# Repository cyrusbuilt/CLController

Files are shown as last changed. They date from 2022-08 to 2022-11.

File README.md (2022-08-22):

# CLController

ESP8266-based Christmas Lights Controller (Arduino)



The code in this repository represents the firmware for the CLController main module, as well as some components for integrating with [OpenHAB3](https://openhab.org). CLController is a [PlatformIO](https://platformio.org) project and is meant to essentially a multi-module outlet controller, with the idea being that you can control multiple string of traditional Christmas light strings (this is not a pixel controller). Given the hardware design however, it is possible to use this device for multiple applications.  I can be monitored and controlled via [MQTT](https://mqtt.org).  Since there is an [ESP8266](https://www.adafruit.com/product/2471) at the heart of it, that means it is WiFi-enabled and is capable of OTA (Over-the-Air) firmware and configuration updates.

## Theory of Operation

CLController consists of one or more combinations of the following 3 hardware components:
- CLController Main Board
- CLController Relay Module
- CLController I/O Expansion Module

The bare-minimum configuration would be the CLController Main Board and (1) Relay Module.  Each relay module allows control of up to 8 circuits at 10A (MAX) per cicuit. The main control board allows up to (2) Relay Modules to be connected to it providing a total of 16 switched circuits.  You can expand this further by connecting an I/O expansion module (up to 7 max - providing a total of 128 possible relays max).  Each expansion module allows you to daisy chain another expansion module and also supports 2 more relay modules per expansion module. The expansion modules connect using the 2-Wire (I2C) bus and are address-configurable (the main control module is hard-wired for address 0x20).  Each expansion module is auto-detected and intialized during boot.

CLController uses a concept of "Playsheets" which is basically a JSON file containing a collection of sequences that fire the relays in the appropriate order at the appropriate time.  Each "sequence" contains a list of "states" followed by a delay in milliseconds.  Each "state" contains the relay module index, light string index (relay number), and state ("on/off").

The following is an example of the playsheet schema:

```json
{
    "name": "Example",
    "seq": [
        {
            "states": [
                {
                    "modIdx": 0,
                    "lsIdx": 1,
                    "lsState": "on"
                },
                ...
            ],
            "delayMs": 600
        },
        ...
    ]
}
```

- name = The play sheet name.
- seq = An array of sequences.
- states = An array of states.
- modIdx = Relay Module Index. 0 is the first relay module (port A on the main board).
- lsIdx = Light String Index. This is the index (address) of the relay to control (1 - 8).
- lsState = The state to set "on" or "off".
- delayMs = The delay in milliseconds before transitioning to the next state.

## IMPORTANT NOTE:

The size of the playsheet you can load will be limited to the amount of RAM available at runtime. If your playsheet (sequence file) is too large, it will fail to load when the controller boots and will report this condition to the serial console. In a future firmware release, the controller will also indicate this as it's status so it can be seen in the status payload published to MQTT and/or indicated using a flashing "RUN" LED or something like that.

## Architecture

CLController currently uses an ESP8266 MCU at it's heart. Unfortunately, the ESP8266 does not have a large number of GPIO pins. So to control the number of relays we need to, the main board (and the I/O expansion board) includes an MCP23017 2 port (8 GPIOs per port) I2C I/O expander paired with (2) ULN2803 Darlington arrays (each provides 8 outputs). The ULN2803s act as relay drivers. Thus allowing us to control up to 16 relays per expander. You can have a maximum of (8) MCP23017 chips on the I2C bus at a time, allowing for a grand total of 128 possible relays per CLController.  You can, of course, set up multiple CLController boards on your network allowing for even more control, but currently, the CLController boards do not communicate with each other and have no way of sharing playsheets. That being said.... if you need to control more than 128 strings of lights on one controller... you have a very impressive setup and an even more impressive utility bill. It's possible that you could break up the sequences across multiple playsheets and send each sheet to each CLController involved OTA, then send the run command to all the controllers over MQTT.  There might be timing issues depending on how long it takes each controller to recieve the command and begin executing though, but something to consider.

## Configuration

The config.h file contains default configuration directives. These options are the hardcoded default values that the system will initially boot with. However, if there is a config.json file present in the root of the SPIFFS file system, then it will override these defaults. Here we'll discuss each option:

- ENABLE_OTA: If you do not wish to support OTA updates, just comment this define.
- ENABLE_MDNS: If you do not wish to support [MDNS](https://tttapa.github.io/ESP8266/Chap08%20-%20mDNS.html), comment this define.
- ENABLE_TLS: If you wish to use TLS support (MQTT-over-SSL), uncomment this define.
- CONFIG_FILE_PATH: This is the path to the configuration file. The default is /config.json. The values in this file will override these defaults.
- DEFAULT_SSID: Change this line to reflect the SSID of your WiFi network.
- DEFAULT_PASSWORD: Change this line to reflect the password to your WiFi network.
- CLOCK_TIMEZONE: The GMT offset for your timezone (EST [America/New York] is -4 when observing DST. It's -5 when not.)
- SERIAL_BAUD: While it is not recommended, you can change the BAUD rate of the serial port here.
- CHECK_WIFI_INTERVAL: The interval (in milliseconds) to check to make sure the device is still connected to WiFi, and if not attempt to reconnect. Default is 30 seconds.
- CHECK_SENSORS_INTERVAL: The interval (in millisceonds) to check the water depth.
- CLOCK_SYNC_INTERVAL: The interval (in milliseconds) to try to resync the clock with NTP. Default is 1 hour.
- DEVICE_NAME: This essentially serves as the host name of the device on the network.
- CHECK_MQTT_INTERVAL: The interval (in milliseconds) to check connectivity to the MQTT broker. If the connection is lost, a reconnect will occur. The default value is 35 seconds.
- MQTT_TOPIC_STATUS: The MQTT status topic to publish device status messages to. Default is 'cysump/status'.
- MQTT_TOPIC_CONTROL: The MQTT control topic to subscribe to for control messages. Default is 'cysump/control'.
- MQTT_BROKER: The hostname or IP of the MQTT broker.
- MQTT_PORT: The port on the MQTT broker to connect to. The default is 8883 (default port for MQTT over TLS).
- OTA_HOST_PORT: Defines the port to listen for OTA updates on. This option is ignored if ENABLE_OTA is disabled.
- OTA_PASSWORD: The password used to authenticate with the OTA server. This option is ignored if ENABLE_OTA is disabled.
- ip: The default IP address. By default, this devices boots with a static IP configuration. The default IP is 192.168.0.202. You can change that here if you wish.
- gw: The default gateway address. The current default is 192.168.0.1. You can change that here if you wish.
- sm: The subnet mask. By default, it is 255.255.255.0, but you can change that here if need be.

To override the default configuration options, you need to upload a filesystem image containing a file named 'config.json' in the root of the SPIFFS filesystem. The file should like something like this:

```json
{
    "hostname": "CLCONTROLLER",
    "useDHCP": false,
    "ip": "192.168.0.202",
    "gateway": "192.168.0.1",
    "subnetMask": "255.255.255.0",
    "dnsServer": "192.168.0.1",
    "wifiSSID": "your_ssid_here",
    "wifiPassword": "your_password_here",
    "webserverPort": 80,
    "otaPort": 8266,
    "otaPassword": "your_ota_password_here",
    "mqttBroker": "your_mqtt_broker_here",
    "mqttPort": 8883,
    "mqttControlChannel": "clcontroller/control",
    "mqttStatusChannel": "clcontroller/status",
    "mqttUsername": "your_mqtt_username",
    "mqttPassword": "your_mqtt_password"
}
```

This configuration file is pretty self explanatory and one is included in the source. The file *MUST* be located in the "data" directory located in the root of the project in order to be picked up by the flash uploader (either via Serial or OTA). Each of the options in the configuration file are self-explanatory and match up with the hard-coded default settings mentioned above. If this file is not present when the firmware boots, a new file will be created and populated with the hardcoded defaults. These defaults can then be changed via the fail-safe menu and saved. You'll notice a couple of additional options in the config.json file not present in config.h. They are as follows:

- mqttUsername: If you have enabled password authentication on your MQTT broker, provide the username here.
- mqttPassword: If you have enabled password authentication on your MQTT broker, provide the password for the username above. If *both* the username and password are provided, then CLController will attempt to connect to the broker with the provided credentials; Otherwise, it will attempt to connect without credentials.
- mqttControlChannel: The MQTT control topic to subscribe to in order to receive device commands.
- mqttStatusChannel: The MQTT status topic to publish device status to.

## Getting Started

After you've configured everything the way you need it (as discussed above), build the firmware by either clicking "Build" in the PlatformIO tasks menu, or by opening a terminal to the project directory and typing:

```bash
> platformio run
```

NOTE: The first time you flash the Huzzah, you need to do so over serial (since the OTA code isn't there yet), but subsequent uploads can be done via OTA if configured properly.

The next thing to do is connect the Huzzah to your computer using an FTDI cable like [this one](https://www.adafruit.com/product/70?gclid=EAIaIQobChMIm7-50ZiZ5AIVlIvICh284QPxEAQYBCABEgJkcPD_BwE) and then configure the port in platformio.ini like so:

```ini
[env:huzzah]
monitor_speed = 115200
monitor_port = /dev/cu.usbserial-AL05HSL2  ; Change this to match your port if necessary
```

With the above mentioned FTDI cable attached to my MacBook, the port appears as it does in the config file above (usually PlatformIO is pretty good about auto-detecting the port for you).

Now all you have to do is flash the firmware onto the Huzzah. You can do this by first pressing and holding the "GPIO" button and then press the "reset" button and let go of both on the Huzzah to put it into flash mode (this is not necessary when you flash via OTA), then click the "Upload and Monitor" task in the PlatformIO menu or by typing the following into the terminal:

```bash
> platformio run --target upload
> platformio device monitor --baud 115200 --port /dev/cu.usbserial-AL05HSL2
```

Once complete, press the "reset" button on the Huzzah. You should see the device boot up in the serial console. Now put the device back into flash mode.  Configure the playsheet.json and config.json files as needed and click the "Upload File System Image" task in the PlatformIO menu. When finished, press the "reset" button again and the device will reboot and come back up with your new configuration settings.

## OTA Updates

If you wish to be able to upload firmware updates Over-the-Air, then besides leaving the ENABLE_OTA option uncommented, you will also need to uncomment all the upload_* lines in platformio.ini, and change the line 'upload_port = ' line to reflect the IP of the device and the line '--auth=' to reflect whatever OTA_PASSWORD is set to. Then when you click "upload" from the PlatformIO tasks (or if you execute 'platformio run --target upload' from the command line) it should upload directly over WiFi and once completed, the device will automatically flash itself and reboot with the new version. If you wish to upload a new configuration file, you can also do this via OTA. Assuming the above-mentioned settings are configured, you can then click "Upload File System Image" from the PlatformIO project tasks.

## Serial Console

If the device ever fails to connect to WiFi or if you press the 'I' key on your keyboard while in the serial console, normal operation of the device is suspended and the device will fall into a 'fail-safe' mode and present the user with a command menu, which can be use to re-configure the device, reboot, manually turn lights on and off, etc.

## Dependencies

The firmware dependencies will be installed automatically at compile-time. However, if you wish to install dependencies prior to compiling (for intellisense or to clear warnings/errors in the VSCode editor) you can run the following command:

```bash
> platformio lib install
```

## Actually controlling the Christmas lights

This is the dangerous part.  The generaly idea is to use the relays to switch strings of lights on and off.  There are a number of ways to do this:

1) Splice into the outlet wiring of an existing outlet/power strip/etc.
2) Cut one or more extension cords and wire into the relays.
3) Cut one of the power wires on the light strings themselves and wire into the relays.
4) Use a bussed electrical circuit that uses the relays to switch individual circuits (my preferred choice).

DISCLAIMER: You are dealing with HIGH VOLTAGE here.  Mains wiring is absolutely lethal and I AM NOT LIABLE for any injuries or death or damage to property as a result of any mistakes you or anyone else make implementing this controller in any way, shape, or form. If you don't know what you are doing, DON'T DO IT. Ask a qualified engineer or electrician to do this part for you. That being said, the way I did it was to mount all the electronics in an empty electrical box using stand-offs. Then I mounted 3 high-voltage electrical bus bars like those found in a breaker box. I then bought a heavy duty extension cord that can handle at least 15 Amps @ 120 Volts AC and cut the end off. I wired the 3 leads into the 3 different bus bars (which were mounted with sufficient distance from each other). Then I bought 16 lower-grade cheap extension cords and cut the plugs off and wired the ground and neutral wires into the matching bus bars. I wired the hot wire from each into the numbered terminals on the relays and then labeled each extension cord. I then cut pieces of heavy guage wire and used those to wire the COM on each relay to the Hot bus bar.  That way I can plug the box into a 15A outlet and then plug each string into the separate extension cord coming out of the box. (If you do this, you need to verify the outlet you are plugging into provides at least 15A and there is no other load on that circuit that would lead to an overload... It might even be worth adding a fuse to the input on the box to be extra safe).  This essentially creates power distribution box similar to a breaker box except you are using relays instead of breakers.

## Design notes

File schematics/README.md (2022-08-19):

# CLController Schematics

All files were produced using [EasyEDA](https://easyeda.com/). The following is a list of files and what they are:

- CLController/COM_CLController.csv - The bill of materials in CSV format.
- CLController/PCB_CLController.pdf - A PDF version of the PCB view.
- CLController/SCH_CLController.pdf - A PDF version of the schematic view.
- CLController/PCB_CLController.json - The original EasyEDA CAD file of the schematic.
- CLController/SCH_CLController.json - The original EasyEDA CAD file of the PCB.
- CLController/gerber - Subdirectory containing the exported Gerber files useful for importing into other CAD programs or for sending to fab houses that do not support EasyEDA files.
- ExpansionModule/* - All of the same things as above, but for the I/O expansion module.
- RelayModule/* - All of the same things as above, but for the relay module.

## NOTES

The MCU used in Rev 1.x of CLController is an Adafruit Huzzah ESP8266.  Future versions of CLController may switch to using an ESP32-based MCU because it is dual-core. Currently, (as is the case with most Arduino-compatible SoCs) there is only one core and only one main loop.  All processing happens on this main loop. While the playsheet processing loop is running, the other subsystems have to wait (task manager, MQTT message processing, OTA request processing, etc) until a sequence delay finishes. All subsystem operations are in their own loop so they can be called from the playsheet sequence processing loop as well as from the main loop() method. This way we can still process everything else, ableit delayed. A better solution would be to use a multi-core MCU like the ESP32 so that the sequence processing can execute on a separate core and not interfere with processing all the other subsystems.

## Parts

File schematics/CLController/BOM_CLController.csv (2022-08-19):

ID | Name | Designator | Footprint | Quantity | Manufacturer Part | Manufacturer | Supplier | Supplier Part | Price
1 | LED 5MM YELLOW | 1 | LED 5MM YELLOW | 1
2 | 100nF | C1,C2,C3,C4 | 100NF | 4 | CT4-0805Y104M500 | ReliaPro | LCSC | C46756
3 | 5mm | D1 | PKG-LED-5MM-RED | 1 | L-1503EC | KINGBRIGHT | Element14 | 1003201
4 | LED-GREEN-2.54-5mm | D2 | LED-GREEN-2.54-5MM-YUN | 1 | 503UOC
5 | Header-Male-2.54_1x6 | H1 | HDR-TH_6P-P2.54-V-M-1 | 1 | Header-Male-2.54_1x6 | BOOMELE | LCSC | C37208 | 0.028
6 | M023.5MM | JP1,JP2 | SCREWTERMINAL-3.5MM-2 | 2
7 | ICSP | P1,P2 | HDR-IDC-2.54-2X5P | 2 | IDC Box 2.54mm 2X5P | BOOMELE | LCSC | C5665 | 0.073
8 | 150 | R1 | PKG-0.25W RESISTOR | 1 | MCF 0.25W 150R | MULTICOMP | Element14 | 9339175
9 | KSH7079_4.7KΩ | R2 | KSH7079_4.7KR | 1 | MFR0W4F2200A50 | UniOhm | EasyEDA | E57439
10 | MCP23017-E/SP | U1 | DIP-28_L35.0-W6.5-P2.54-LS7.6-BL | 1 | MCP23017-E/SP | Microchip Tech | LCSC | C647352 | 2.279
11 | Huzzah ESP8266 Breakout_TT | U2 | HUZZAH 8266 | 1 |  | Adafruit
12 | ULN2803APG | U3,U4 | ULN2803APG | 2 | ULN2803APG | TOSHIBA | LCSC | C5252

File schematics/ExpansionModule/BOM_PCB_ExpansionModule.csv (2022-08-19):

ID | Name | Designator | Footprint | Quantity | Manufacturer Part | Manufacturer | Supplier | Supplier Part | Price
1 | 100nF | C1,C2,C3,C4 | 100NF | 4 | CT4-0805Y104M500 | ReliaPro | LCSC | C46756
2 | M023.5MM | JP1,JP2,JP3 | SCREWTERMINAL-3.5MM-2 | 3
3 | ICSP | P1,P2 | HDR-IDC-2.54-2X5P | 2 | IDC Box 2.54mm 2X5P | BOOMELE | LCSC | C5665 | 0.073
4 | KSH7079_4.7KΩ | R3,R1,R2 | KSH7079_4.7KR | 3 | MFR0W4F2200A50 | UniOhm | EasyEDA | E57439
5 | 150 | R4 | PKG-0.25W RESISTOR | 1 | MCF 0.25W 150R | MULTICOMP | Element14 | 9339175
6 | MCP23017-E/SP | U1 | DIP-28_L35.0-W6.5-P2.54-LS7.6-BL | 1 | MCP23017-E/SP | Microchip Tech | LCSC | C647352 | 2.279
7 | 5mm | D1 | PKG-LED-5MM-RED | 1 | L-1503EC | KINGBRIGHT | Element14 | 1003201
8 | HEADER MALE 1X3 | J1,J2,J3,J4,J5 | HEADER MALE OR FEMALE PINS 1X3 | 5
9 | ULN2803APG | U2,U3 | ULN2803APG | 2 | ULN2803APG | TOSHIBA | LCSC | C5252
10 | 470 | R5 | RESISTOR 1/4 WATT 470 OHM | 1
11 | LM317T | U4 | TO-220 (LM317T) | 1 | LM317T | ON | Mouser | 511-LM317T
12 | 100uF 25v | C6 | 100UF/25V | 1 | -
13 | 330 | R6 | RESISTOR 1/4 WATT 330 OHM | 1
14 | 75Ω(75R0) | R7 | AXIAL-0.3 | 1 | MF1/8W-75Ω±1% T52 | CCO | LCSC | C119155 | 0.008
15 | 10uF | C5 | CAP-10UF-50V-CHONGX | 1 | 10uF 50V白纸 13*25 | ValuePro | LCSC | C43814 | 0.155

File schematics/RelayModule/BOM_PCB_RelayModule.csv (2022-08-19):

ID | Name | Designator | Footprint | Quantity | Manufacturer Part | Manufacturer | Supplier | Supplier Part | Price
1 | G5LE-14 5VDC | K1,K2,K3,K4,K5,K6,K7,K8 | RELAY-TH_G5LE-14-XX | 8 | - | Omron Electronics | LCSC | C116963 | 1.646
2 | LED-GREEN-2.54-5mm | D1,D2,D3,D4,D5,D6,D7,D8 | LED-GREEN-2.54-5MM-YUN | 8 | 503UOC
3 | 5mm | D9 | PKG-LED-5MM-RED | 1 | L-1503EC | KINGBRIGHT | Element14 | 1003201
4 | ICSP | P1 | HDR-IDC-2.54-2X5P | 1 | IDC Box 2.54mm 2X5P | BOOMELE | LCSC | C5665 | 0.073
5 | M023.5MM | JP1,JP2,JP3,JP4,JP5,JP6,JP7,JP8 | SCREWTERMINAL-3.5MM-2 | 8
6 | 4114R-002-151 | IC1 | DIP-14_L17.8-W10.2-P2.54-BL | 1 | 100-143-200-1001-00 | Nextron(台湾正凌) | LCSC | C2846065 | 0.252

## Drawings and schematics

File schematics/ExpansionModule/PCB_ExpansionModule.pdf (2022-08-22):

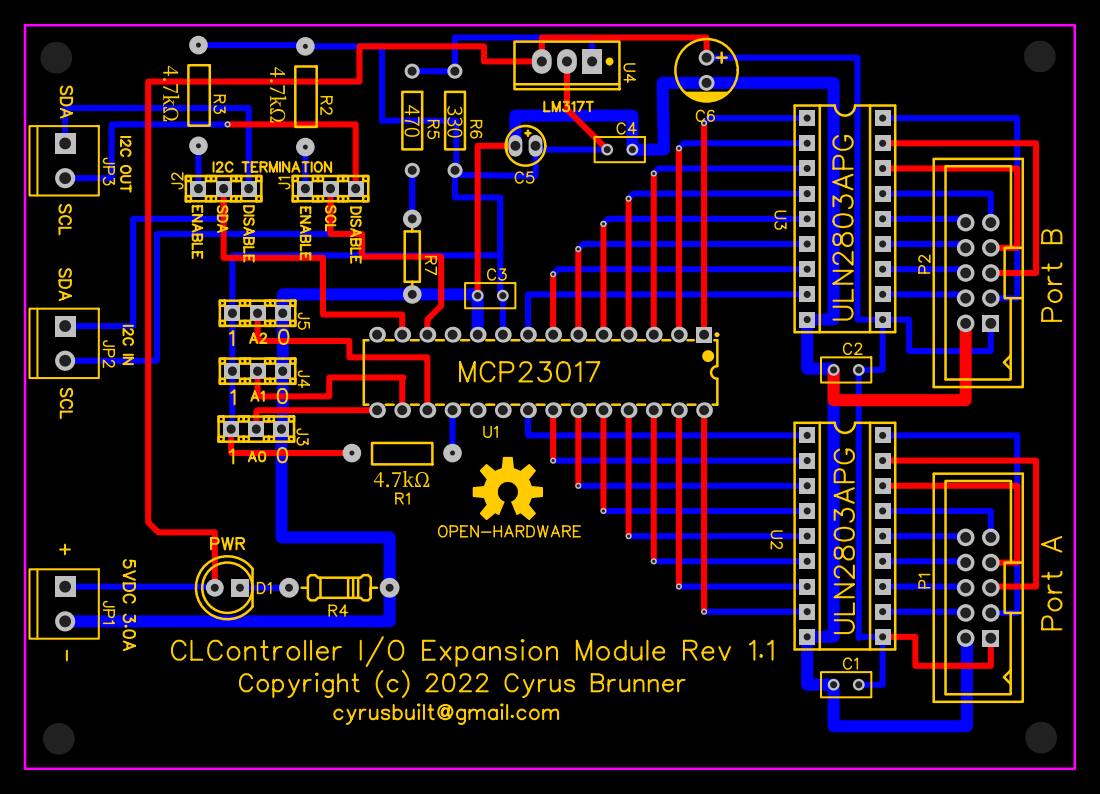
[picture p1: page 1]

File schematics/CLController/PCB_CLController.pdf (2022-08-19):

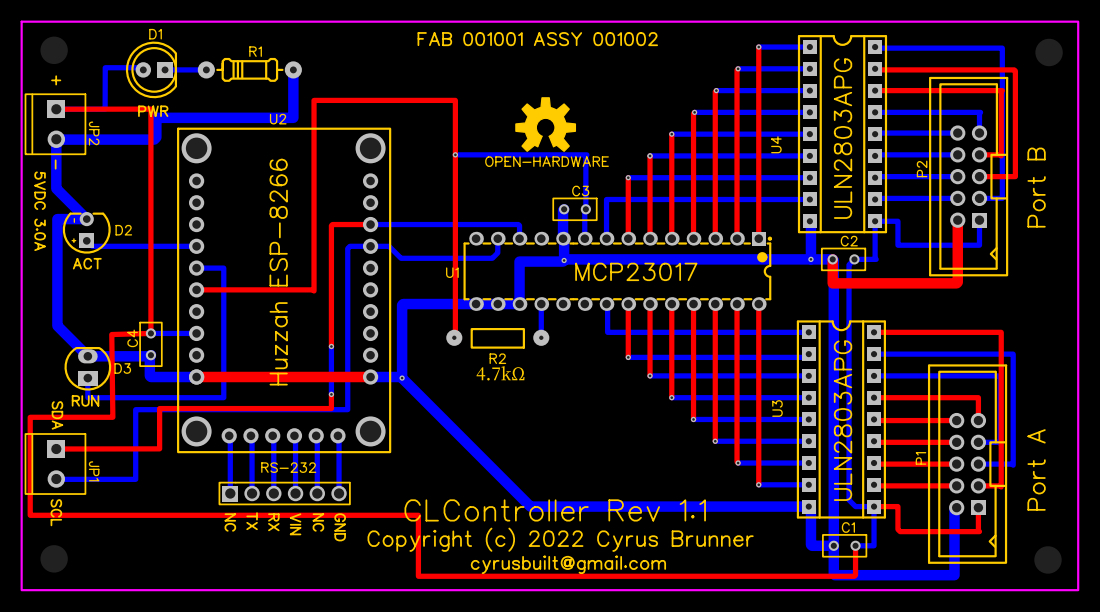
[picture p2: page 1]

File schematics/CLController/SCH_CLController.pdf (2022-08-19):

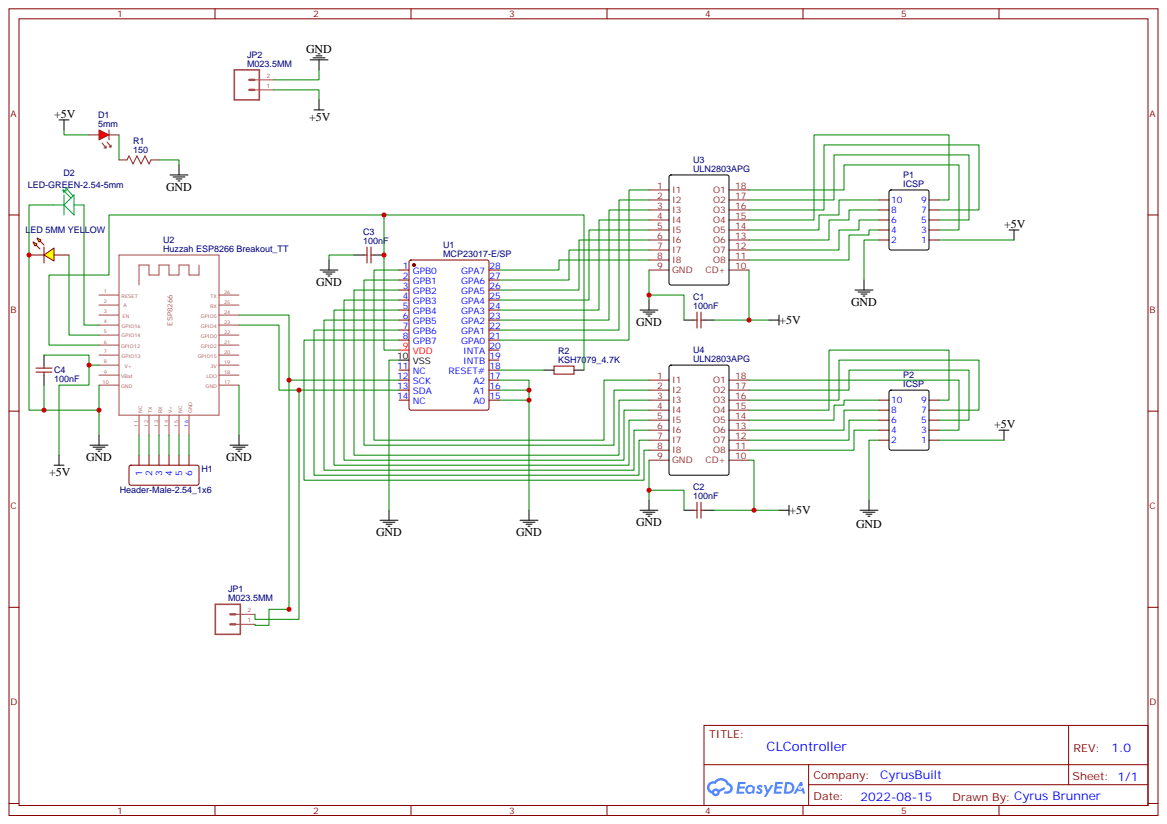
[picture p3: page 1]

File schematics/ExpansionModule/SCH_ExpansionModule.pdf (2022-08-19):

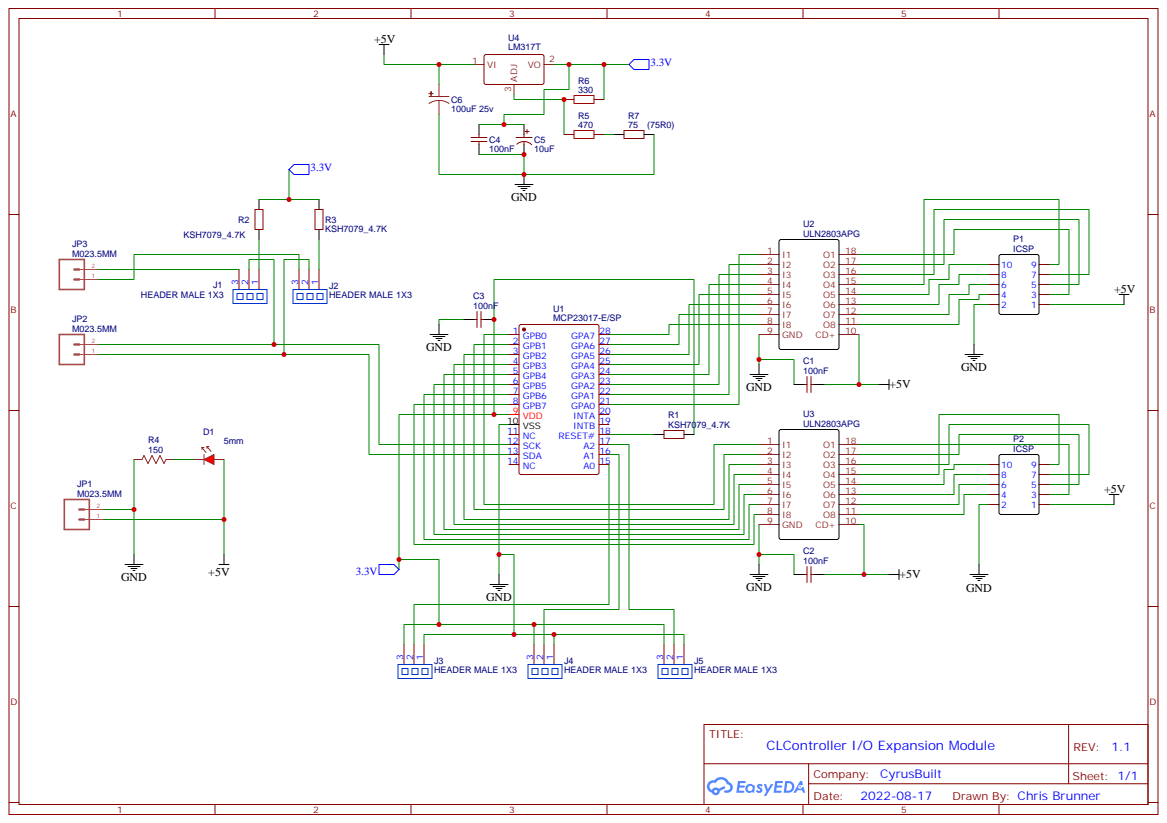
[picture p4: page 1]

Drawn By: Chris Brunner

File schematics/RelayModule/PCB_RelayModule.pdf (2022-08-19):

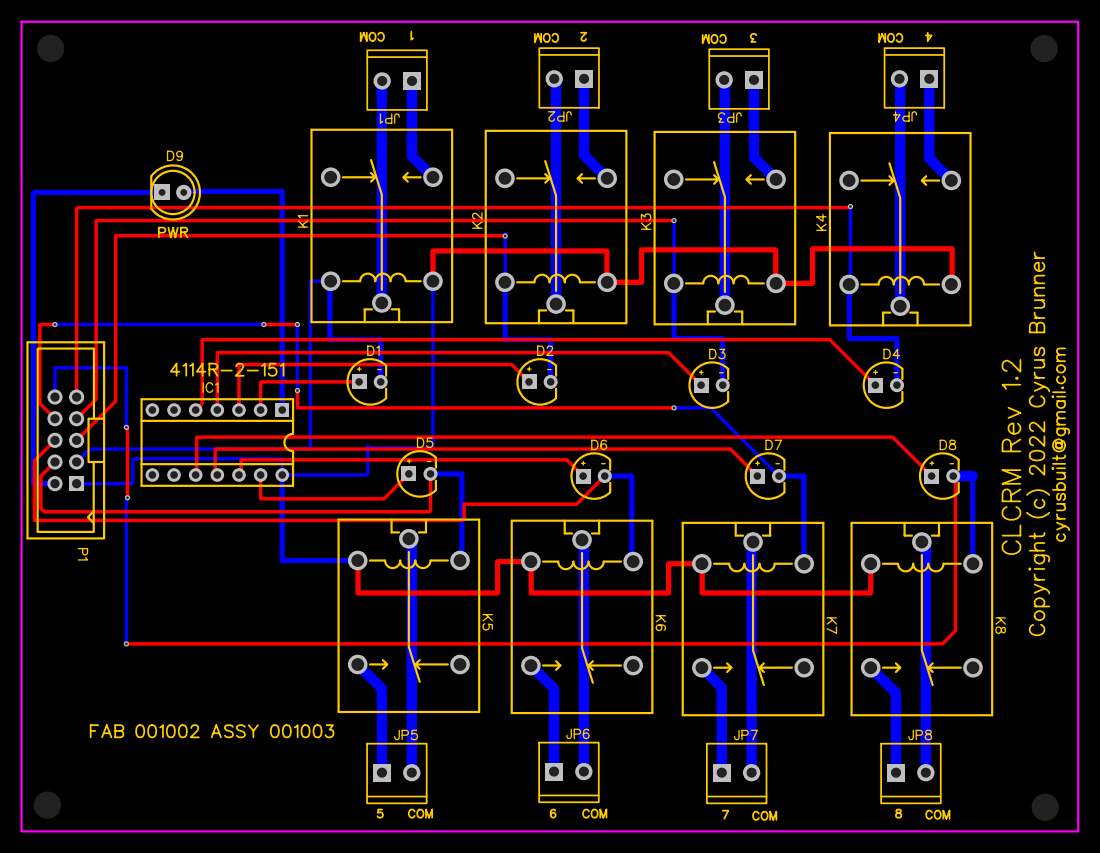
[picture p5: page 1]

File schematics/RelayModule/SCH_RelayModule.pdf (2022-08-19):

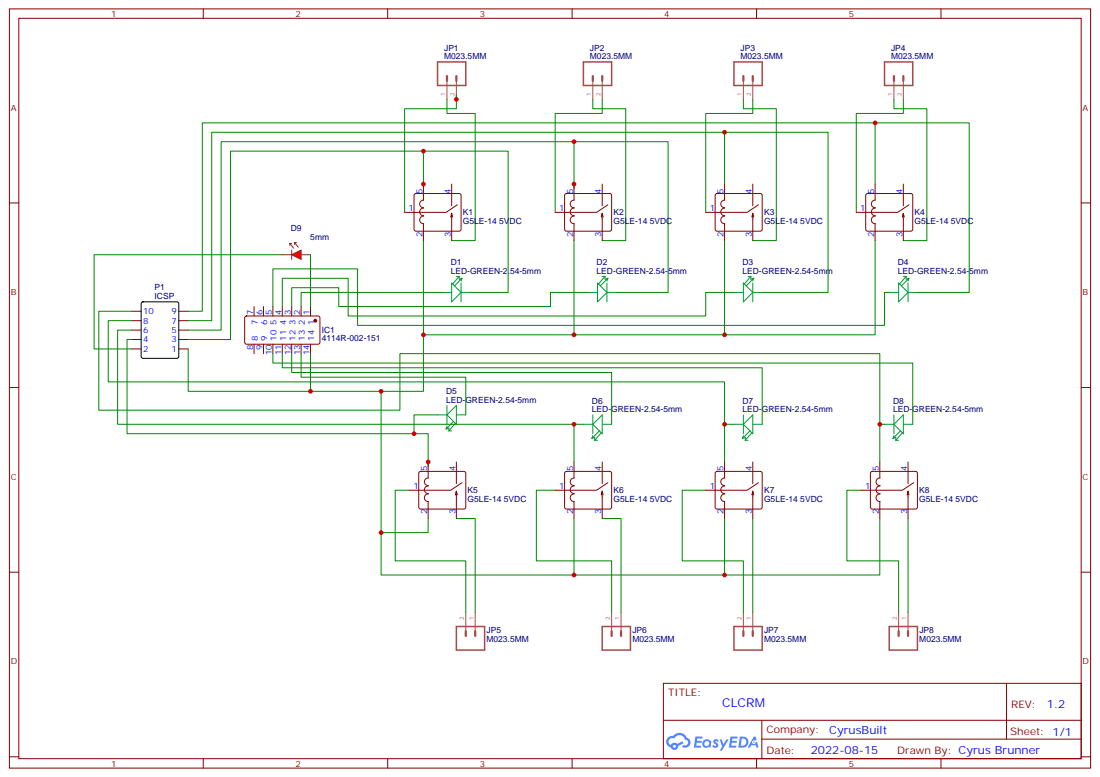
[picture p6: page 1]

Drawn By: Cyrus Brunner

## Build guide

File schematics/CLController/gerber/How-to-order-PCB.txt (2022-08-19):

How to Order PCB

Please refer to:
https://docs.easyeda.com/en/PCB/Order-PCB

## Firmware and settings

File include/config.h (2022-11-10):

#ifndef CONFIG_H
#define CONFIG_H

#include <IPAddress.h>

//#define MODEL_1                                     // The Model 1 controller used 5 PowerRelay FeatherWing modules instead of RelayModule over I2C.
#define DEBUG                                       // Enable additional debug output.
#define DEVICE_NAME "CLCONTROLLER"                  // The device name (hostname).
#define DEVICE_CLASS "clcontroller"                 // The device class (used for discovery).
#define BAUD_RATE 115200                            // The BAUD rate (speed) of the serial port (console).
#define ENABLE_OTA                                  // Comment to disable OTA (over-the-air) firmware updates.
#define ENABLE_MDNS                                 // Comment to disable MDNS (multicast-DNS) support.
#define CONFIG_FILE_PATH "/config.json"             // Config file path. Do not alter unless you are sure.
#define PLAYSHEET_FILE_PATH "/playsheet.json"       // Playsheet file path. Do not alter unless you are sure.
#define DEFAULT_SSID "your_ssid_here"               // Put the SSID of your WiFi here.
#define DEFAULT_PASSWORD "your_wifi_password"       // Put your WiFi password here.
#define CLOCK_TIMEZONE -4                           // The timezone this device is located in. (For example, EST when observing DST = GMT -4, when not = GMT -5).
#define CHECK_WIFI_INTERVAL 30000                   // How often to check WiFi status (millis)
#define CLOCK_SYNC_INTERVAL 3600000                 // How often to sync the local clock with NTP (millis)
#define CHECK_MQTT_INTERVAL 35000                   // MQTT connectivity check interval (millis).
#define MQTT_TOPIC_STATUS "clcontroller/status"     // MQTT status channel to publish to.
#define MQTT_TOPIC_CONTROL "clcontroller/control"   // MQTT control channel to subscribe to.
#define MQTT_TOPIC_DISCOVERY "redqueen/config"      // MQTT discovery topic to publish to.
#define MQTT_BROKER "your_mqtt_broker_ip"           // MQTT broker hostname or IP.
#define MQTT_PORT 8883                              // MQTT port number.
#ifdef ENABLE_OTA
    #include <ArduinoOTA.h>
    #define OTA_HOST_PORT 8266                      // The OTA updater port.
    #define OTA_PASSWORD "your_ota_password_here"   // The OTA updater password.
#endif
const IPAddress defaultIp(192, 168, 0, 215);                     // Default static IP address.
const IPAddress defaultGw(192, 168, 0, 1);                       // Default static gateway address.
const IPAddress defaultSm(255, 255, 255, 0);                     // Default static subnet mask.
const IPAddress defaultDns(192, 168, 0, 1);                      // Default static primary DNS address.

typedef struct {
    // Network stuff
    String hostname;
    String ssid;
    String password;
    IPAddress ip;
    IPAddress gw;
    IPAddress sm;
    IPAddress dns;
    bool useDhcp;

    uint8_t clockTimezone;
    String sheetName;

    // MQTT stuff
    String mqttTopicStatus;
    String mqttTopicControl;
    String mqttTopicDiscovery;
    String mqttBroker;
    String mqttUsername;
    String mqttPassword;
    uint16_t mqttPort;

    // OTA stuff
    uint16_t otaPort;
    String otaPassword;
} config_t;

#endif

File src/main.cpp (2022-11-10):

/**
 * @file main.cpp
 * @author Cyrus Brunner (cyrusbuilt at gmail dot com)
 * @brief CLController Firmware
 * 
 * I/O Expansion:
 * 
 * The main controller board has an MCP23017 which provides 16 digital
 * GPIOs and is located at PRIMARY_I2C_ADDRESS. This is what controls the 8 outputs
 * on each of the 2 ports on the main board.  However, it is possible to expand
 * this even further by adding additional MCP23017s (7 additional max) on the I2C bus.
 * As such, the main board provides a 2-pin I2C header that additional expanders to connect to.
 * @version 1.2
 * @date 2022-11-10
 * 
 * @copyright Copyright (c) 2022 Cyrus Brunner
 */

// TODO Possible design changes:
// 1) Change ESP8266 to ESP32
// 2) Split up into further modules - 1] Main controller board. 2] I/O module (MCP3017 and ULN2803). 3] Relay modules. -- Done
// 3) Create abstraction library for relay module (it's essentially an 8bit interface).  -- Done
// 4) Come up with a way to detect relay module presence. -- Done (sort of)
// 12/2/2020 - There is no way to do #4 without adding additional circuitry to the relay module and at least
// one I/O per module for sense.  This can be done by keeping the original design but removing one relay per
// module and using that I/O as an input tied to VSS via a resistor (5.6K ?).  The MCP23017 does not have any
// analog pins, so we can't do an analog read to get resistance. We can only look for low/high. That being said,
// the firmware currently (unreliably) does this by checking to see if the pin on the MCP23017 is LOW after INIT
// (indicating the pin is not floating, the default state).

#include <Arduino.h>
#include <FS.h>
#include <time.h>
#include <vector>
#include "ArduinoJson.h"
#include "ESPCrashMonitor.h"
#include "Console.h"
#include "LED.h"
#include "PubSubClient.h"
#include "ResetManager.h"
#include "TaskScheduler.h"
#include "TelemetryHelper.h"
#include "config.h"
#ifdef MODEL_1
#include "Relay.h"
#else
#include <Wire.h>
#include "Adafruit_MCP23017.h"
#include "RelayModule.h"
#endif
#include "Playsheet.h"

#define FIRMWARE_VERSION "1.2"

// This firmware provides backward compatibility with the original (Model 1)
// CLController board which just consisted of an Adafruit Huzzah ESP8266 and
// 5 Adafruit PowerRelay FeatherWings. By uncommenting the MODEL_1 define in
// config.h, this firmware can be configured for the old controller board.
#ifdef MODEL_1
#define PIN_RELAY_5 12
#define PIN_RELAY_4 13
#define PIN_RELAY_3 14
#define PIN_RELAY_2 16
#define PIN_RELAY_1 15
#define PIN_WIFI_LED 2
#else
#define PRIMARY_I2C_ADDRESS 0
#define I2C_ADDRESS_OFFSET 32
#define PIN_WIFI_LED 16
#define PIN_RUN_LED 14
#define PIN_BUS_ENABLE 12
#endif

#ifdef MODEL_1
enum class RelaySelect : uint8_t {
    RELAY1 = 1,
    RELAY2 = 2,
    RELAY3 = 3,
    RELAY4 = 4,
    RELAY5 = 5
};
#endif

using namespace std;

// Forward declarations.
void operationsLoop();
void onCheckWifi();
void onCheckMqtt();
void onSyncClock();
void onMqttMessage(char* topic, byte* payload, unsigned int length);

// Global vars.
#ifdef ENABLE_MDNS
    #include <ESP8266mDNS.h>
    MDNSResponder mdns;
#endif
WiFiClient wifiClient;
PubSubClient mqttClient(wifiClient);
Task tCheckWiFi(CHECK_WIFI_INTERVAL, TASK_FOREVER, &onCheckWifi);
Task tCheckMqtt(CHECK_MQTT_INTERVAL, TASK_FOREVER, &onCheckMqtt);
Task tClockSync(CLOCK_SYNC_INTERVAL, TASK_FOREVER, &onSyncClock);
Scheduler taskMan;
#ifdef MODEL_1
vector<Relay> relays;
#else
bool primaryExpanderFound = false;
vector<byte> devicesFound;
vector<Adafruit_MCP23017> additionalBusses;
vector<RelayModule> relayModules;
Adafruit_MCP23017 primaryBus;
LED runLED(PIN_RUN_LED, NULL);
#endif
LED wifiLED(PIN_WIFI_LED, NULL);
config_t config;
bool filesystemMounted = false;
volatile bool terminateSequence = false;
volatile SystemState sysState = SystemState::BOOTING;

/**
 * @brief Get the current time.
 * 
 * @return String The current date/time in UTC in string format.
 */
String getCurrentTime() {
    time_t now = time(nullptr);
    struct tm *timeinfo = localtime(&now);
    return String(asctime(timeinfo));
}

/**
 * @brief Synchronize the local system clock via NTP. Note: This does not take
 * DST into account. Currently, you will have to adjust the CLOCK_TIMEZONE
 * define manually to account for DST when needed.
 */
void onSyncClock() {
    wifiLED.on();
    configTime(config.clockTimezone * 3600, 0, "pool.ntp.org", "time.nist.gov");

    Serial.print("INIT: Waiting for NTP time sync...");
    delay(500);
    while (!time(nullptr)) {
        wifiLED.off();
        ESPCrashMonitor.iAmAlive();
        Serial.print(F("."));
        delay(500);
        wifiLED.on();
    }

    wifiLED.off();
    Serial.println(F(" DONE"));
    Serial.print(F("INFO: Current time: "));
    Serial.println(getCurrentTime());
}

/**
 * @brief Publishes the current system state to the configured status topic if
 * connected to the MQTT broker.
 */
void publishSystemState() {
    if (mqttClient.connected()) {
        wifiLED.on();

        DynamicJsonDocument doc(200);
        doc["client_id"] = config.hostname.c_str();
        doc["firmwareVersion"] = FIRMWARE_VERSION;
        doc["systemState"] = (uint8_t)sysState;
        doc["playingSequence"] = !terminateSequence;
        doc["sheetName"] = config.sheetName;

        String jsonStr;
        size_t len = serializeJson(doc, jsonStr);
        Serial.print(F("INFO: Publishing system state: "));
        Serial.println(jsonStr);
        if (!mqttClient.publish(config.mqttTopicStatus.c_str(), jsonStr.c_str(), len)) {
            Serial.println(F("ERROR: Failed to publish message."));
        }

        doc.clear();
        wifiLED.off();
    }
}

/**
 * @brief Publishes a device discovery packet to the configured discovery topic.
 */
void publishDiscoveryPacket() {
    if (mqttClient.connected()) {
        wifiLED.on();

        DynamicJsonDocument doc(250);
        doc["name"] = config.hostname;
        doc["class"] = DEVICE_CLASS;
        doc["statusTopic"] = config.mqttTopicStatus;
        doc["controlTopic"] = config.mqttTopicControl;

        String jsonStr;
        size_t len = serializeJson(doc, jsonStr);
        Serial.print(F("INFO: Publishing discovery packet: "));
        Serial.println(jsonStr);
        if (!mqttClient.publish(config.mqttTopicDiscovery.c_str(), jsonStr.c_str(), len)) {
            Serial.println(F("ERROR: Failed to publish message."));
        }

        doc.clear();
        wifiLED.off();
    }
}

/**
 * @brief Resume normal operation. This will resume any suspended tasks.
 */
void resumeNormal() {
    Serial.println(F("INFO: Resuming normal operation..."));
    taskMan.enableAll();
    wifiLED.off();
    #ifndef MODEL_1
    runLED.off();
    #endif
    sysState = SystemState::NORMAL;
    terminateSequence = false;
    publishSystemState();
}

/**
 * @brief Prints network information details to the serial console.
 */
void printNetworkInfo() {
    Serial.print(F("INFO: Local IP: "));
    Serial.println(WiFi.localIP());
    Serial.print(F("INFO: Gateway: "));
    Serial.println(WiFi.gatewayIP());
    Serial.print(F("INFO: Subnet mask: "));
    Serial.println(WiFi.subnetMask());
    Serial.print(F("INFO: DNS server: "));
    Serial.println(WiFi.dnsIP());
    Serial.print(F("INFO: MAC address: "));
    Serial.println(WiFi.macAddress());
    #ifdef DEBUG
        WiFi.printDiag(Serial);
    #endif
}

/**
 * @brief Scan for available networks and dump each discovered network to the
 * console.
 */
void getAvailableNetworks() {
    ESPCrashMonitor.defer();
    Serial.println(F("INFO: Scanning WiFi networks..."));
    int numNetworks = WiFi.scanNetworks();
    for (int i = 0; i < numNetworks; i++) {
        Serial.print(F("ID: "));
        Serial.print(i);
        Serial.print(F("\tNetwork name: "));
        Serial.print(WiFi.SSID(i));
        Serial.print(F("\tSignal strength:"));
        Serial.println(WiFi.RSSI(i));
    }
    Serial.println(F("----------------------------------"));
}

/**
 * @brief Resets the MCP23017 I2C GPIO expander.
 */
void busReset() {
    Serial.println(F("WARN: Performing bus reset ..."));
    digitalWrite(PIN_BUS_ENABLE, LOW);
    delay(500);
    digitalWrite(PIN_BUS_ENABLE, HIGH);
    delay(500);
}

/**
 * @brief Performs a soft-reboot.
 */
void reboot() {
    busReset();
    Serial.println(F("INFO: Rebooting..."));
    Serial.flush();
    delay(1000);
    ResetManager.softReset();
}

/**
 * @brief Persists the current running configuration in memory to the config.json
 * file in flash.
 */
void saveConfiguration() {
    Serial.print(F("INFO: Saving configuration to "));
    Serial.print(CONFIG_FILE_PATH);
    Serial.println(F(" ... "));
    if (!filesystemMounted) {
        Serial.println(F("FAIL"));
        Serial.println(F("ERROR: Filesystem not mount."));
        return;
    }

    StaticJsonDocument<350> doc;
    doc["hostname"] = config.hostname;
    doc["useDhcp"] = config.useDhcp;
    doc["ip"] = config.ip.toString();
    doc["gateway"] = config.gw.toString();
    doc["subnetmask"] = config.sm.toString();
    doc["dnsServer"] = config.dns.toString();
    doc["wifiSSID"] = config.ssid;
    doc["wifiPassword"] = config.password;
    doc["mqttBroker"] = config.mqttBroker;
    doc["mqttPort"] = config.mqttPort;
    doc["mqttControlTopic"] = config.mqttTopicControl;
    doc["mqttStatusTopic"] = config.mqttTopicStatus;
    doc["mqttDiscoveryTopic"] = config.mqttTopicDiscovery;
    doc["mqttUsername"] = config.mqttUsername;
    doc["mqttPassword"] = config.mqttPassword;
    #ifdef ENABLE_OTA
        doc["otaPort"] = config.otaPort;
        doc["otaPassword"] = config.otaPassword;
    #endif

    File configFile = SPIFFS.open(CONFIG_FILE_PATH, "w");
    if (!configFile) {
        Serial.println(F("FAIL"));
        Serial.println(F("ERROR: Failed to open config file for writing."));
        doc.clear();
        return;
    }

    serializeJsonPretty(doc, configFile);
    doc.clear();
    configFile.flush();
    configFile.close();
    Serial.println(F("DONE"));
}

/**
 * @brief Prints a warning to the console.
 * 
 * @param message The message to print.
 */
void printWarningAndContinue(const __FlashStringHelper *message) {
    Serial.println();
    Serial.println(message);
    Serial.print(F("INFO: Continuing... "));
}

/**
 * @brief Sets the running configuration in memory to the factory defaults.
 */
void setConfigurationDefaults() {
    String chipId = String(ESP.getChipId(), HEX);
    String defHostname = String(DEVICE_NAME) + "_" + chipId;

    config.hostname = defHostname;
    config.ip = defaultIp;
    config.mqttBroker = MQTT_BROKER;
    config.mqttPassword = "";
    config.mqttPort = MQTT_PORT;
    config.mqttTopicControl = MQTT_TOPIC_CONTROL;
    config.mqttTopicStatus = MQTT_TOPIC_STATUS;
    config.mqttTopicDiscovery = MQTT_TOPIC_DISCOVERY;
    config.mqttUsername = "";
    config.password = DEFAULT_PASSWORD;
    config.sm = defaultSm;
    config.ssid = DEFAULT_SSID;
    config.useDhcp = false;
    config.clockTimezone = CLOCK_TIMEZONE;
    config.dns = defaultDns;
    config.gw = defaultGw;
    config.sheetName = "";

    #ifdef ENABLE_OTA
        config.otaPassword = OTA_PASSWORD;
        config.otaPort = OTA_HOST_PORT;
    #endif
}

/**
 * @brief Loads the configuration from the config.json file in local flash
 * to the running configuration in memory.
 */
void loadConfiguration() {
    memset(&config, 0, sizeof(config));

    Serial.print(F("INFO: Loading config file "));
    Serial.print(CONFIG_FILE_PATH);
    Serial.print(F(" ... "));
    if (!filesystemMounted) {
        Serial.println(F("FAIL"));
        Serial.println(F("ERROR: Filesystem not mounted."));
        return;
    }

    if (!SPIFFS.exists(CONFIG_FILE_PATH)) {
        Serial.println(F("FAIL"));
        Serial.println(F("WARN: Config file does not exist. Creating with default config ..."));
        saveConfiguration();
        return;
    }

    File configFile = SPIFFS.open(CONFIG_FILE_PATH, "r");
    if (!configFile) {
        Serial.println(F("FAIL"));
        Serial.println(F("ERROR: Unable to open config file. Using default config."));
        return;
    }

    size_t size = configFile.size();
    uint16_t freeMem = ESP.getMaxFreeBlockSize() - 512;
    if (size > freeMem) {
        Serial.println(F("FAIL"));
        Serial.print(F("ERROR: Not enough free memory to load document. Size = "));
        Serial.print(size);
        Serial.print(F(", Free = "));
        Serial.println(freeMem);
        configFile.close();
        return;
    }

    DynamicJsonDocument doc(freeMem);
    DeserializationError error = deserializeJson(doc, configFile);
    if (error) {
        Serial.println(F("FAIL"));
        Serial.println(F("ERROR: Fail to parse config file to JSON. Using default config."));
        configFile.close();
        return;
    }

    doc.shrinkToFit();
    configFile.close();

    String chipId = String(ESP.getChipId(), HEX);
    String defHostname = String(DEVICE_NAME) + "_" + chipId;

    config.hostname = doc.containsKey("hostname") ? doc["hostname"].as<String>() : defHostname;
    config.useDhcp = doc.containsKey("isDhcp") ? doc["isDhcp"].as<bool>() : false;
    
    if (doc.containsKey("ip")) {
        if (!config.ip.fromString(doc["ip"].as<String>())) {
            printWarningAndContinue(F("WARN: Invalid IP in configuration. Falling back to factory default."));
        }
    }
    else {
        config.ip = defaultIp;
    }

    if (doc.containsKey("gateway")) {
        if (!config.gw.fromString(doc["gateway"].as<String>())) {
            printWarningAndContinue(F("WARN: Invalid gateway in configuration. Falling back to factory default."));
        }
    }
    else {
        config.gw = defaultGw;
    }

    if (doc.containsKey("subnetmask")) {
        if (!config.sm.fromString(doc["subnetmask"].as<String>())) {
            printWarningAndContinue(F("WARN: Invalid subnet mask in configuration. Falling back to factory default."));
        }
    }
    else {
        config.sm = defaultSm;
    }

    if (doc.containsKey("dns")) {
        if (!config.dns.fromString(doc["dns"].as<String>())) {
            printWarningAndContinue(F("WARN: Invalid DNS IP in configuration. Falling back to factory default."));
        }
    }
    else {
        config.dns = defaultDns;
    }

    config.ssid = doc.containsKey("wifiSSID") ? doc["wifiSSID"].as<String>() : DEFAULT_SSID;
    config.password = doc.containsKey("wifiPassword") ? doc["wifiPassword"].as<String>() : DEFAULT_PASSWORD;
    config.mqttBroker = doc.containsKey("mqttBroker") ? doc["mqttBroker"].as<String>() : MQTT_BROKER;
    config.mqttPort = doc.containsKey("mqttPort") ? doc["mqttPort"].as<int>() : MQTT_PORT;
    config.mqttTopicControl = doc.containsKey("mqttControlTopic") ? doc["mqttControlTopic"].as<String>() : MQTT_TOPIC_CONTROL;
    config.mqttTopicStatus = doc.containsKey("mqttStatusTopic") ? doc["mqttStatusTopic"].as<String>() : MQTT_TOPIC_STATUS;
    config.mqttTopicDiscovery = doc.containsKey("mqttDiscoveryTopic") ? doc["mqttDiscoveryTopic"].as<String>() : MQTT_TOPIC_DISCOVERY;
    config.mqttUsername = doc.containsKey("mqttUsername") ? doc["mqttUsername"].as<String>() : "";
    config.mqttPassword = doc.containsKey("mqttPassword") ? doc["mqttPassword"].as<String>() : "";

    #ifdef ENABLE_OTA
        config.otaPort = doc.containsKey("otaPort") ? doc["otaPort"].as<uint16_t>() : MQTT_PORT;
        config.otaPassword = doc.containsKey("otaPassword") ? doc["otaPassword"].as<String>() : OTA_PASSWORD;
    #endif

    doc.clear();
    Serial.println(F("DONE"));
}

/**
 * @brief Performs a "factory restore" of the running configuration. This is
 * done by first deleting the config.json file in flash and rebooting the
 * MCU. On startup, the running config will fallback to the factory defaults
 * which will the then be persisted to a new config.json file.
 */
void doFactoryRestore() {
    Serial.println();
    Serial.println(F("Are you sure you wish to restore to factory default? (Y/n)"));
    Console.waitForUserInput();
    
    String str = Console.getInputString();
    if (str == "Y" || str == "y") {
        Serial.print(F("INFO: Clearing current config... "));
        if (filesystemMounted) {
            if (SPIFFS.remove(CONFIG_FILE_PATH)) {
                Serial.println(F("DONE"));
                Serial.print(F("INFO: Removed file: "));
                Serial.println(CONFIG_FILE_PATH);

                Serial.print(F("INFO: Rebooting in "));
                for (uint8_t i = 5; i >= 1; i--) {
                    Serial.print(i);
                    Serial.print(F(" "));
                    delay(1000);
                }

                reboot();
            }
            else {
                Serial.println(F("FAIL"));
                Serial.println(F("ERROR: Failed to delete cofiguration file."));
            }
        }
        else {
            Serial.println(F("FAIL"));
            Serial.println(F("ERROR: Filesystem not mounted."));
        }
    }

    Serial.println();
}

/**
 * @brief Loads the "play sheet" into memory.
 */
void loadSequenceSheet() {
    Serial.print(F("INFO: Loading sequence file: "));
    Serial.print(PLAYSHEET_FILE_PATH);
    Serial.print(F(" ..."));

    if (!filesystemMounted) {
        Serial.println(F("FAIL"));
        Serial.println(F("ERROR: Filesystem not mounted."));
        terminateSequence = true;
        return;
    }

    if (!SPIFFS.exists(PLAYSHEET_FILE_PATH)) {
        Serial.println(F("FAIL"));
        Serial.println(F("ERROR: Sequence file does not exist."));
        terminateSequence = true;
        return;
    }

    File sequenceFile = SPIFFS.open(PLAYSHEET_FILE_PATH, "r");
    if (!sequenceFile) {
        Serial.println(F("FAIL"));
        Serial.println(F("ERROR: Unable to open sequence file."));
        terminateSequence = true;
        return;
    }

    // Do we have enough free contiguous memory to load the file?
    size_t size = sequenceFile.size();
    #ifdef DEBUG
        Serial.println();
        Serial.print(F("DEBUG: Playsheet file size: "));
        Serial.println(size);
    #endif
    uint16_t freeMem = ESP.getMaxFreeBlockSize() - 512;
    #ifdef DEBUG
        Serial.print(F("DEBUG: Free memory before load: "));
        Serial.println(freeMem);
    #endif
    if (size > freeMem) {
        Serial.println(F("FAIL"));
        Serial.print(F("ERROR: Not enough free memory to load document. Size = "));
        Serial.print(size);
        Serial.print(F(", Free = "));
        Serial.println(freeMem);
        sequenceFile.close();
        return;
    }

    DynamicJsonDocument doc(freeMem);
    DeserializationError error = deserializeJson(doc, sequenceFile);
    if (error) {
        Serial.println(F("FAIL"));
        Serial.print(F("ERROR: Failed to parse sequence file to JSON: "));
        Serial.println(error.c_str());
        sequenceFile.close();
        return;
    }

    sequenceFile.close();
    doc.shrinkToFit();
    
    config.sheetName = doc["name"].as<String>();
    Playsheet.sheetName = config.sheetName.c_str();
    
    #ifdef MODEL_1
    RelayState newState = RelayOpen;
    const uint8_t modIdx = 0;
    #else
    uint8_t modIdx = 0;
    ModuleRelayState newState = ModuleRelayState::OPEN;
    #endif
    RelaySelect relay = RelaySelect::RELAY1;

    JsonArray sequences = doc["seq"].as<JsonArray>();
    for (auto sequence : sequences) {
        Sequence seq;
        JsonArray states = sequence["states"];
        for (auto state : states) {
            // We don't care about the module index if we're running on a Model 1 controller.
            #ifndef MODEL_1
            modIdx = state["modIdx"].as<uint8_t>();
            #endif
            if (strcmp(state["lsState"].as<const char*>(), "on") == 0) {
                #ifdef MODEL_1
                newState = RelayClosed;
                #else
                newState = ModuleRelayState::CLOSED;
                #endif
            }
            else {
                #ifdef MODEL_1
                newState = RelayOpen;
                #else
                newState = ModuleRelayState::OPEN;
                #endif
            }

            relay = (RelaySelect)state["lsIdx"].as<uint8_t>();
            #ifdef MODEL_1
            SequenceState theState(modIdx, newState, (uint8_t)relay);
            #else
            SequenceState theState(modIdx, newState, relay);
            #endif
            seq.states.push_back(theState);
        }

        seq.delay = sequence["delayMs"].as<unsigned long>();
        Playsheet.sequences.push_back(seq);
    }

    doc.clear();
    #ifdef DEBUG
        freeMem = ESP.getMaxFreeBlockSize() - 512;
        Serial.print(F("DEBUG: Free memory after load: "));
        Serial.println(freeMem);
    #endif
    Serial.println(F("DONE"));
}
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
void loop() {
    operationsLoop();
    if (!terminateSequence) {
        playSequenceSheet();
    }
}

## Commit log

2020-10-28 First real commit
    [CLController.fzz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]
2020-11-05 Fixing relaymodule design. Add configs.
    [RelayModule.fzz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]
2020-11-10 Minor desgin improvements and adding exp mod
    [CLController.fzz, ExpansionModule.fzz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]
2020-12-11 Model 1 support. Fix relay module. Update designs.
    [CLController.fzz, ExpansionModule.fzz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]
2020-12-28 Adding on/off timer support
2022-07-29 Hardware rev 1.1 (Model 2B)
    [CLController.fzz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]
2022-07-29 Adding power LED
    [CLController.fzz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]
2022-08-19 Overhaul hardware design and get rid of TravisCI
    [BOM_CLController.csv, BOM_PCB_ExpansionModule.csv, BOM_PCB_RelayModule.csv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]
2022-08-22 Add label for PWR LED on exp module
    [Gerber_BottomLayer.GBL, Gerber_TopLayer.GTL, Gerber_TopSilkscreenLayer.GTO]
